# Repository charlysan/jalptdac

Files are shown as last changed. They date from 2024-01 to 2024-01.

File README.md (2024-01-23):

# jalptdac

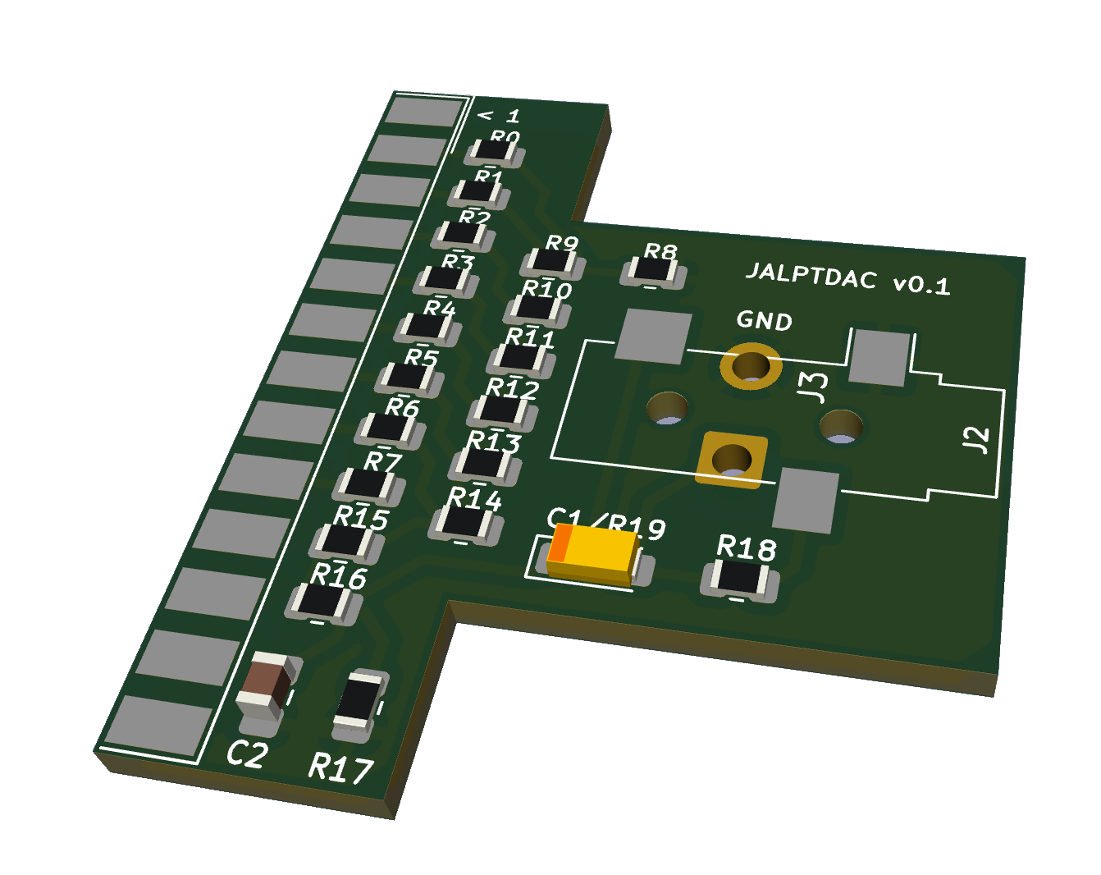
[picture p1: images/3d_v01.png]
3d


Just Another LPT DAC

## Table Of Contents
- [Introduction](#introduction)
- [Design](#design)
- [Schematics (Kicad and Gerber files)](#schematics-kicad-and-gerber-files)
- [Build](#build)
  - [Option #1 (MODPLAY PRO Recommendation)](#option-1-modplay-pro-recommendation)
  - [Option #2 (COVOX)](#option-2-covox)
- [Pictures and videos](#pictures-and-videos)
- [References](#references)

## Introduction

JALPTDAC is a minimalist LPT R-2R DAC that could be assembled within a DSUB-25 connector case. The initial design was inspired by the 1994 [COMPUSOUND interface](https://raw.githubusercontent.com/wiki/charlysan/jalptdac/images/magazine.jpg). The latter appears to be an implementation of the MODPLAY PRO Hardware recommendation:

<p align="center">
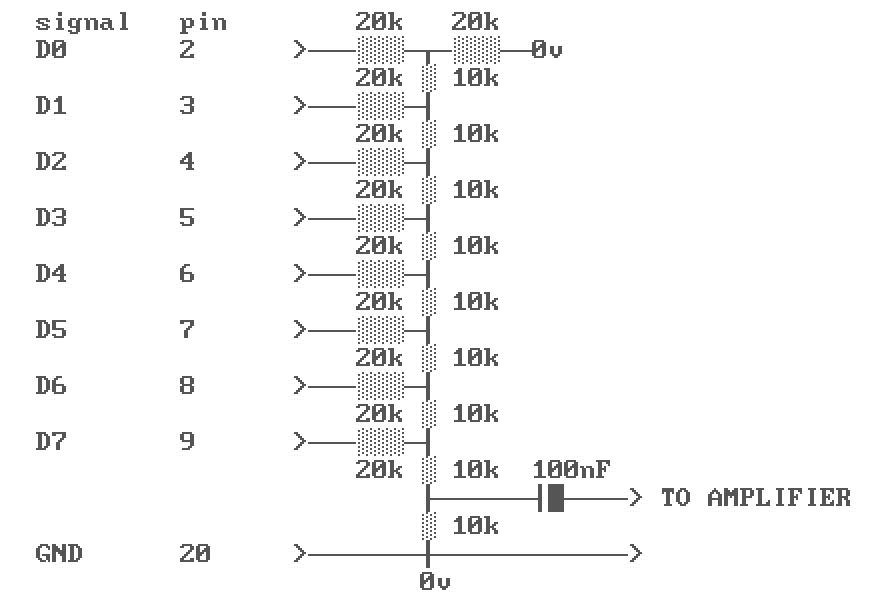
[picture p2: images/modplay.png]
  
</p>

## Design

The design is somehow flexible, allowing you to choose from several alternatives:

1. Solder a cable to the output and enclose the PCB within a case (like COMPUSOUND)
2. Add a 3.5 female plug connector (and use it without the case)
3. Implement MODPLAY PRO approach (R = 10K)
4. Implement original Covox design (R = 100K)

## Schematics (Kicad and Gerber files)

<p align="center">
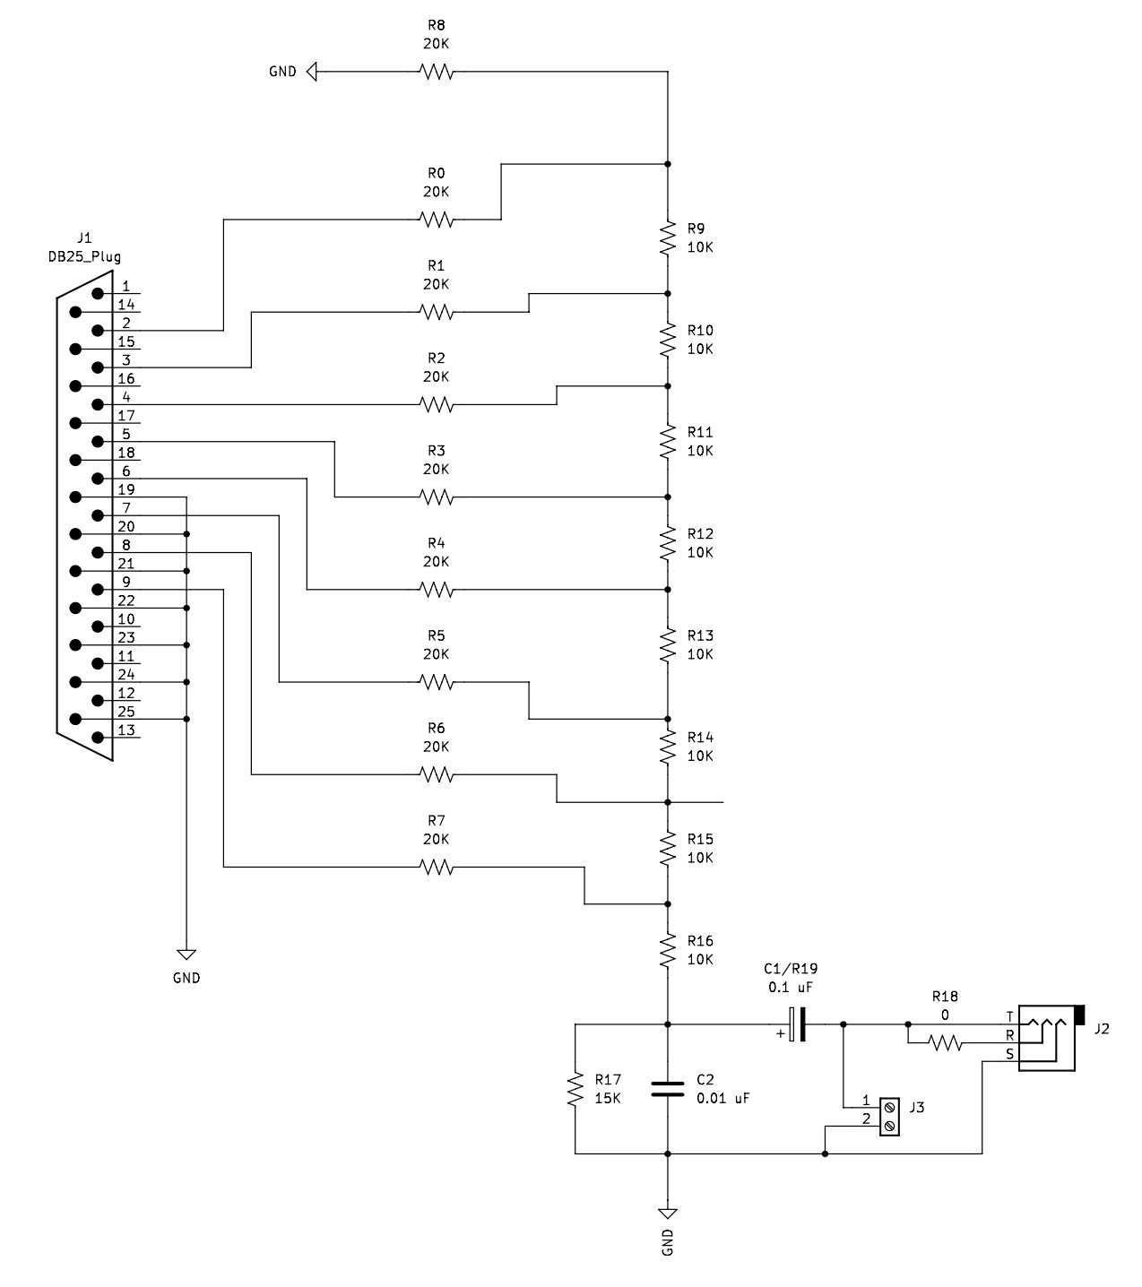
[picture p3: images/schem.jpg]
  
</p>

You can find Kicad files under [./kicad](./kicad/) folder, and Gerber files can be found [here](./kicad/v0.1/gerber/).

## Build

You will need to use high precision resistors (>= 1% tolerance). 

### Option #1 (MODPLAY PRO Recommendation)

| component | Value | Mouser ID | Notes |
|---|---|---|---|
| R0-R8 | 20K - 0.1% | [ERA-6AEB203V](https://mou.sr/48EkaXj) | |
| R9-R16 | 10K - 0.1% | [ERA-6AEB103V](https://mou.sr/3tSAFQK) | |
| R17 | N/A | | |
| R18 | 0 Ohms | [RC0805JR-100RL](https://mou.sr/427Xlci) | (Optional - for dual mono) |
| R19 | N/A | | |
| C1 | 0.1 µF (Polarized)| [T489A104M035ATE20K](https://mou.sr/48ZVXur) | |
| C2 | 0.01 µF | [C0805C103J5RAC7025](https://mou.sr/48YnrR3) | |
| J2 | 3.5 Audio Jack | [SJ-3524-SMT-TR](https://mou.sr/3SrcnWj) | (Optional) |

### Option #2 (COVOX)

| component | Value | Mouser ID | Notes |
|---|---|---|---|
| R0-R7 | 200K - 0.1% | [ERA-6AEB203V](https://mou.sr/48EkaXj) | |
| R8 | N/A | | |
| R9-R15 | 100K - 0.1% | [ERA-6AEB103V](https://mou.sr/3tSAFQK) | |
| R16 | 0 Ohms | [RC0805JR-100RL](https://mou.sr/427Xlci) | |
| R17 | 24K | [6AEB243V](https://mou.sr/424skpI) | |
| R18 | 0 Ohms | [RC0805JR-100RL](https://mou.sr/427Xlci) | (Optional - for dual mono) |
| R19 | 0 Ohms | [RC0805JR-100RL](https://mou.sr/427Xlci) | |
| C1 | N/A | | |
| C2 | 5100 pF | [C0805C512F4HACAUTO](https://mou.sr/48FHVhY) | |
| J2 | 3.5 Audio Jack | [SJ-3524-SMT-TR](https://mou.sr/3SrcnWj) | (Optional) |

**Note**: If you decide to use a 3.5 female plug, you can choose between mono and dual-mono output; for dual-mono just short R18 (or add a 0 Ohms resistor)

## Pictures and videos

[Wiki section](https://github.com/charlysan/jalptdac/wiki) includes some pictures and examples.

## References

- [The Covox Years](https://scalibq.wordpress.com/2017/11/28/the-covox-years/)
- [DOScember Making Covox/DAC Hardware and Software](https://www.youtube.com/watch?v=DfNsAK710kQ)
- [Silly Sound Bastard](https://www.youtube.com/watch?v=DKLKtH_rQJU)

**Special thanks to**: [Scali](https://scalibq.wordpress.com/author/scalibq/page/2/), [CallousCoder](https://www.youtube.com/@CallousCoder), & [Necroware](https://www.youtube.com/@necro_ware)

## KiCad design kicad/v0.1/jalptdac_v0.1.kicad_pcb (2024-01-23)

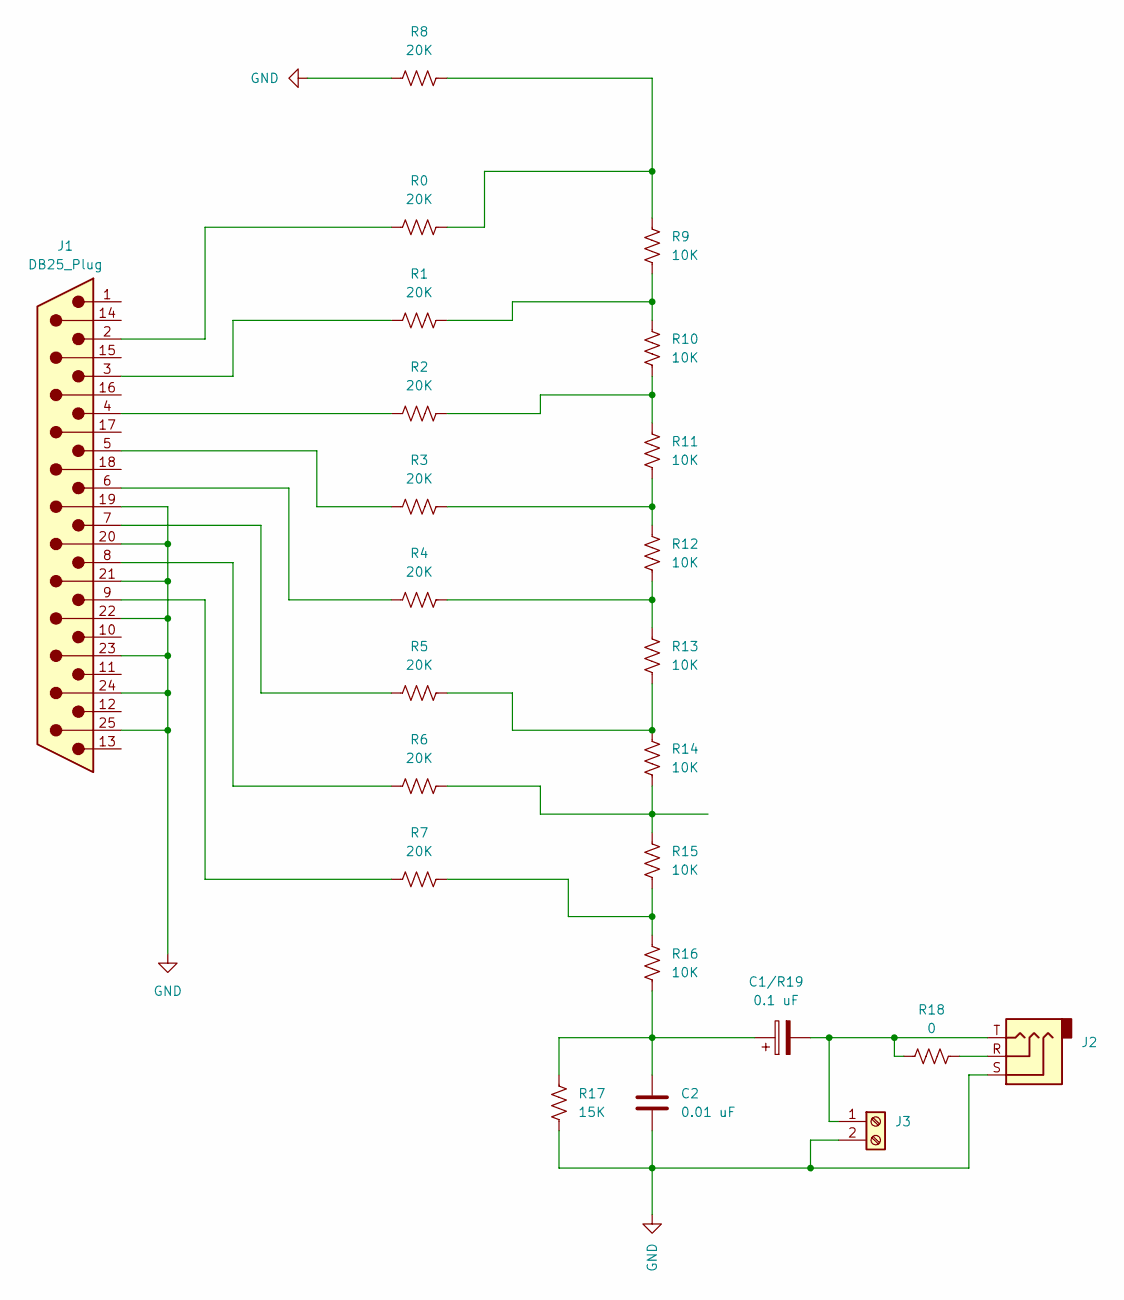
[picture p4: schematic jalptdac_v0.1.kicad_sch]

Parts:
C1/R19: 0.1 uF; CP_EIA-3216-10_Kemet-I_Pad1.58x1.35mm_HandSolder
C2: 0.01 uF; C_0805_2012Metric_Pad1.18x1.45mm_HandSolder
J1: DB25_Plug; DSUB-25_Male_EdgeMount_P2.77mm
J2: AudioJack3; Jack_3.5mm_CUI_SJ-3523-SMT_Horizontal
J3: Connector; SolderWire-0.75sqmm_1x02_P4.8mm_D1.25mm_OD2.3mm
R0, R1, R2, R3, R4, R5, R6, R7, R8: 20K; R_0805_2012Metric
R9, R10, R11, R12, R13, R14, R15, R16: 10K; R_0805_2012Metric
R17: 15K; R_0805_2012Metric
R18: 0; R_0805_2012Metric

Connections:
GND: C2.2, J1.19, J1.20, J1.21, J1.22, J1.23, J1.24, J1.25, J2.S, J3.2, R8.1, R17.1
unnamed: C1/R19.1, C2.1, R16.1, R17.2
unnamed: J1.2, R0.1
unnamed: J1.3, R1.1
unnamed: J1.4, R2.1
unnamed: J1.5, R3.1
unnamed: J1.6, R4.1
unnamed: J1.7, R5.1
unnamed: J1.8, R6.1
unnamed: J1.9, R7.1
unnamed: J2.R, R18.1
unnamed: C1/R19.2, J2.T, J3.1, R18.2
unnamed: R0.2, R8.2, R9.2
unnamed: R1.2, R9.1, R10.2
unnamed: R2.2, R10.1, R11.2
unnamed: R3.2, R11.1, R12.2
unnamed: R4.2, R12.1, R13.2
unnamed: R5.2, R13.1, R14.2
unnamed: R6.2, R14.1, R15.2
unnamed: R7.2, R15.1, R16.2

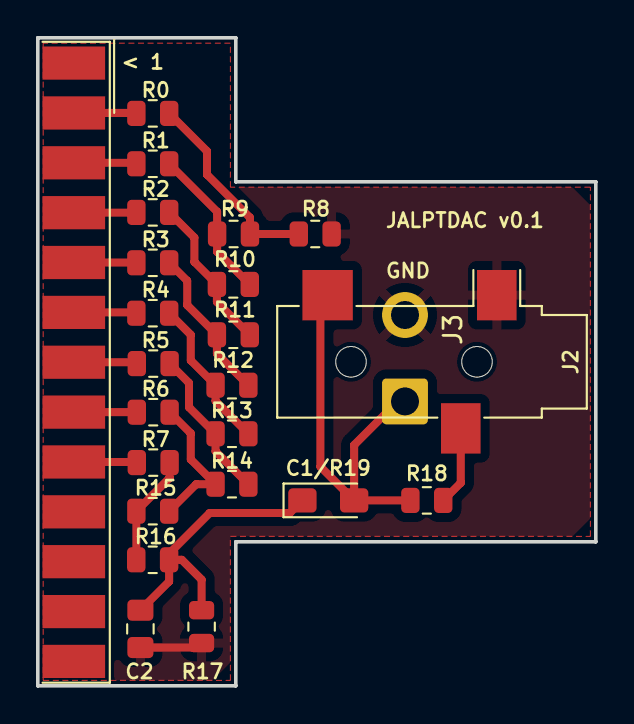
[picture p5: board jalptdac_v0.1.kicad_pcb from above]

Board: 2 copper layers, 31.0 x 36.0 mm, 24 parts (0 on the bottom side), 20 nets.
